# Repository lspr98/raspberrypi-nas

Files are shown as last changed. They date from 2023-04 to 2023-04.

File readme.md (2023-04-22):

# Raspberry Pi NAS Rack for up to 4 2.5"-SSDs
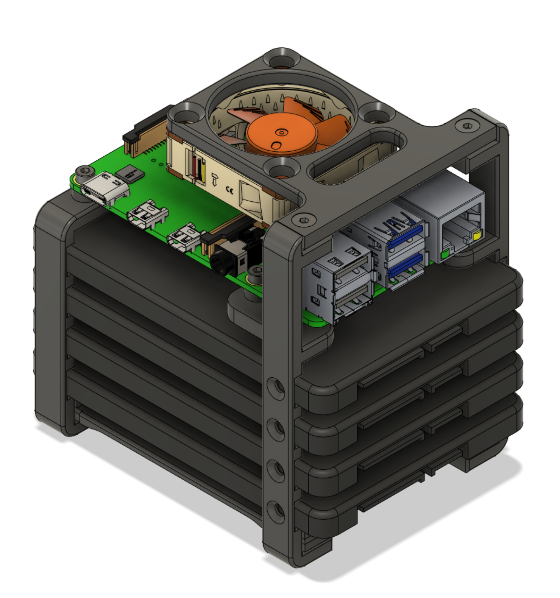
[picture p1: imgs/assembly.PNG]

## Highlights
- **Slim**: The rack is only 4mm wider than a 2.5" SSD and as long as a 2.5" SSD
- **Modular**: 2-bay and 4-bay version available, each with or without fan mount
- **Accessible**: All Raspberry Pi ports/pins are accessible without the fan
- **Ease-Of-Use**: Small nobs secure the SSDs without screws for quick swapping
- **Open-Source**: STEP-File with complete assembly available for easy modding

## Sourcing / BOM
Please refer to the [BOM file](./Sourcing/BOM.xlsx)

## Printing

At least 100mm x 100mm buildplate size is required.

Depending on what version of the NAS rack you want, you need to print different parts:
|Part Name|2-Bay|2-Bay with fan|4-Bay|4-Bay with fan|Support needed|
|---|---|---|---|---|---|
|40mm_fan_mount.stl| |1| |1|No|
|brace_long_side.stl|2|2|2|2|No|
|brace_short_side.stl|2|2|2|2|No|
|column_noshift_noscrew.stl|2|2| | |Touching Buildplate|
|column_noshift_noscrew_QUAD.stl| | |2|2|Touching Buildplate|
|column_shift.stl|1| | | |Touching Buildplate|
|column_shift_mirror.stl|1| | | |Touching Buildplate|
|column_shift_fan.stl| |1| | |Touching Buildplate|
|column_shift_fan_mirror.stl| |1| | |Touching Buildplate|
|column_shift_QUAD.stl| | |1| |Touching Buildplate|
|column_shift_QUAD_mirror.stl| | |1| |Touching Buildplate|
|column_shift_fan_QUAD.stl| | | |1|Touching Buildplate|
|column_shift_fan_QUAD_mirror.stl| | | |1|Touching Buildplate|

These are only recommendations and worked fine on my Ender 3:
|Settings|Value|
|---|---|
|Wall count|4|
|Top/Bottom Layers|4|
|Layer Height|0.2mm|
|Material|PLA|
|Infill|40%|
|Support|Refer to table above|

## Important Notes
When using multiple SSDs, make sure that the accumulated current draw across all USB ports do not surpass the maximum rated output. Also make sure that your power supply can handle the additional power requirements.
|RPi Model|Maximum rated output across all ports|
|---|---|
|Pi 2,3,4|1200mA|

Also consider the shared bandwith of the USB ports.

## CAD Credits
The 3D-models for the Screws, Nuts, SSDs, Raspberry and Fan are from GrabCAD:

|Model|Author|Link|
|---|---|---|
|M3x10 Screw|[Antonio Ghio](https://grabcad.com/antonio.ghio-1)|[Source](https://grabcad.com/library/hex-socket-countersunk-flat-head-screws-m3-1)|
|M3 Nut|[ioan skurka](https://grabcad.com/ioan.skurka-1)|[Source](https://grabcad.com/library/all-m3-sh-standard-screws-m3-hex-nut-and-flat-washer-for-m3-screw-1)|
|M2.5x10 Screw|[VIVEK AKASH](https://grabcad.com/vivek.akash-2)|[Source](https://grabcad.com/library/m2-5-0-45-hex-screw-5-10-15-20-25-30-mm-1)|
|M2.5 Nut|[Antonio Ghio](https://grabcad.com/antonio.ghio-1)|[Source](https://grabcad.com/library/nuts-and-washers-m2-5-1)|
|2.5" SSD|[Thin Pinstripes](https://grabcad.com/thin.pinstripes-1)|[Source](https://grabcad.com/library/u2-2-5in-ssd-1)|
|NF-A4x10 FLX|[Gerard](https://grabcad.com/gerard-84)|[Source](https://grabcad.com/library/noctua-fan-nf-a4x10-flx-4010-1)|
|Raspberry Pi 4 Model B|[Hasanain Shuja](https://grabcad.com/hasanain.shuja-1)|[Source](https://grabcad.com/library/raspberry-pi-4-model-b-1)|

## References
[1]: Rasberry Pi Documentation, [Link](https://www.raspberrypi.com/documentation/computers/raspberry-pi.html#universal-serial-bus-usb)

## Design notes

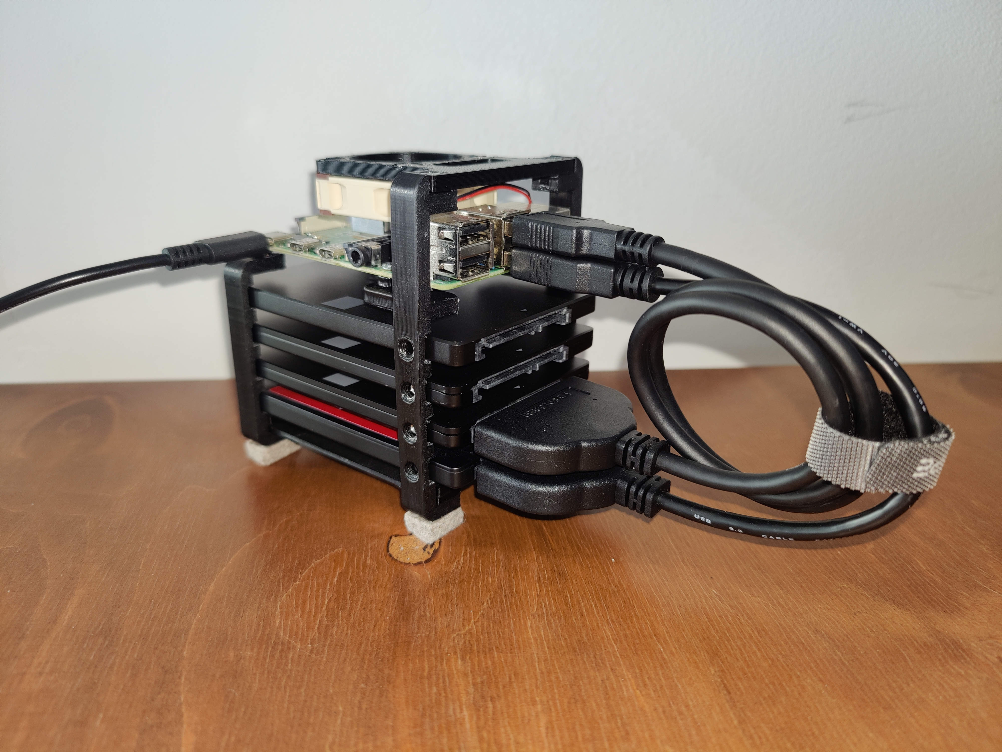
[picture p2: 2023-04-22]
imgs/photo_quad_with_fan.jpg

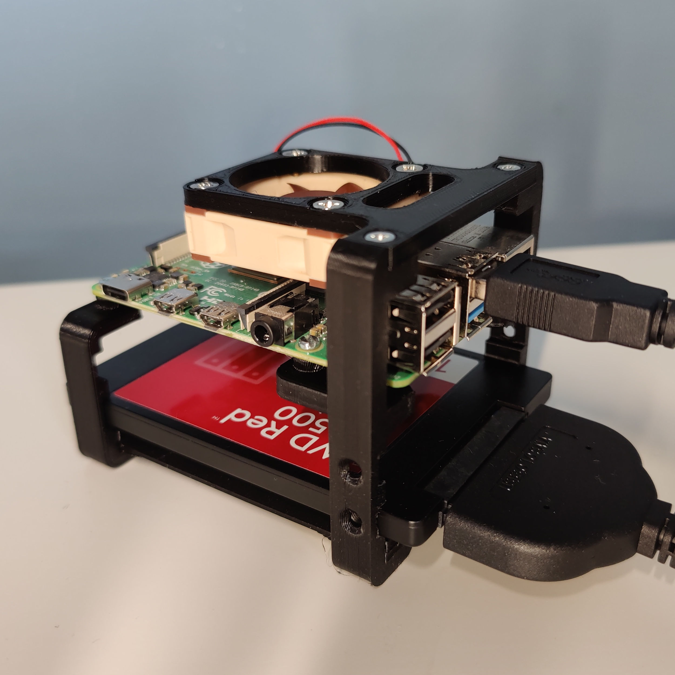
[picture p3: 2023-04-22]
imgs/photo_dual_with_fan.jpg

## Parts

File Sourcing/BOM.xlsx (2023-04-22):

Category | Description | Quantity (without fan) | Quantity (with fan) | Notes
Fasteners | M2.5 Nut | 4 | 4
 | M3 Nut | 4 | 6
 | M2.5x10 Sockethead | 4 | 4
 | M3x10 Countersunk | 4 | 6
 | Fan Mounting Screws | 0 | 4 | These should come with the fan
Elecronics | NF-A10 | 0 | 1
 | Raspberry Pi 1/2/3/4 | 1 | 1 | The rack versions without fan should be compatible with "knock-offs" as long as the mounting holes are identical
 | SATA to USB adapter | 1 to 4 | 1 to 4 | Depending on how many SSDs you plan to install

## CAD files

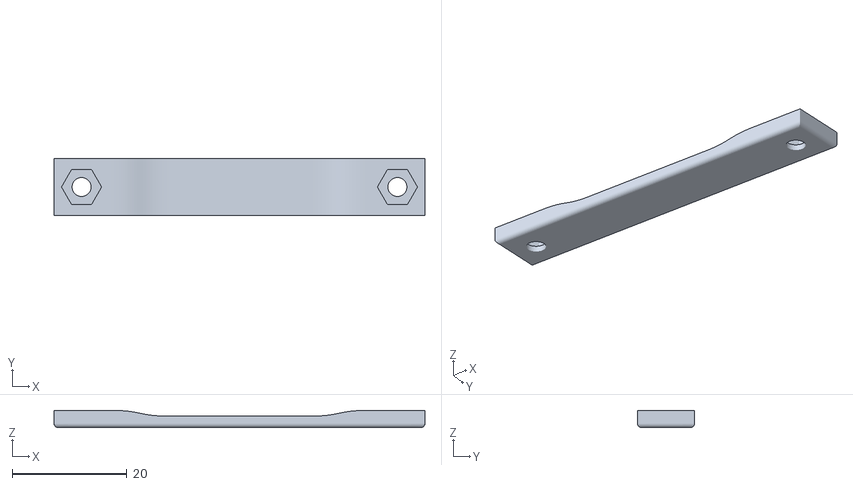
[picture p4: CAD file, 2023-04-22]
STL/brace_short_side.stl
64.6 x 10.0 x 3.00

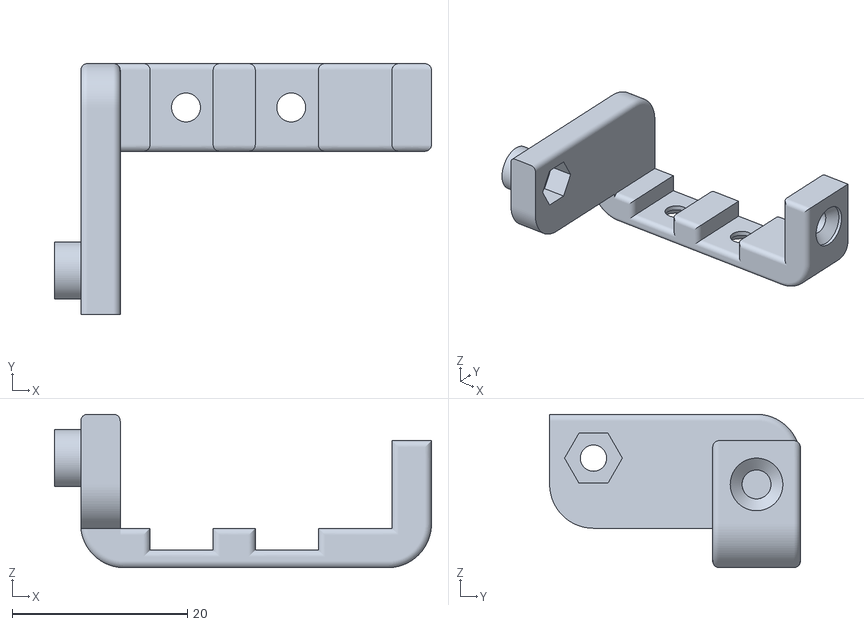
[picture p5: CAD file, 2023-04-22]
STL/column_shift_mirror.stl
43.0 x 28.6 x 17.5

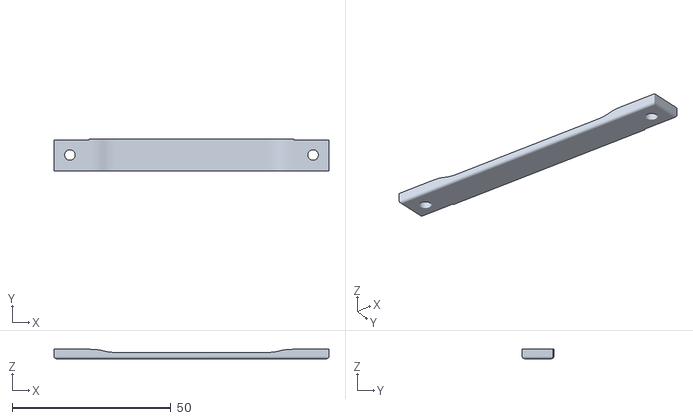
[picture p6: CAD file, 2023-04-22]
STL/brace_long_side.stl
86.6 x 10.0 x 3.00

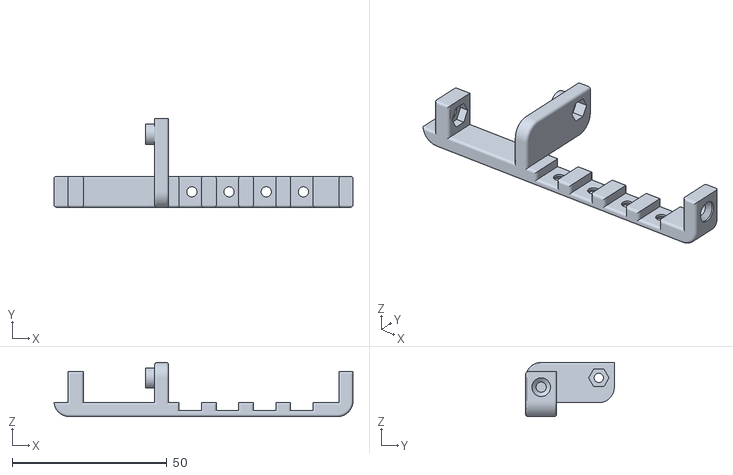
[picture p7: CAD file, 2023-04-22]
STL/column_shift_fan_QUAD.stl
96.5 x 28.6 x 17.5

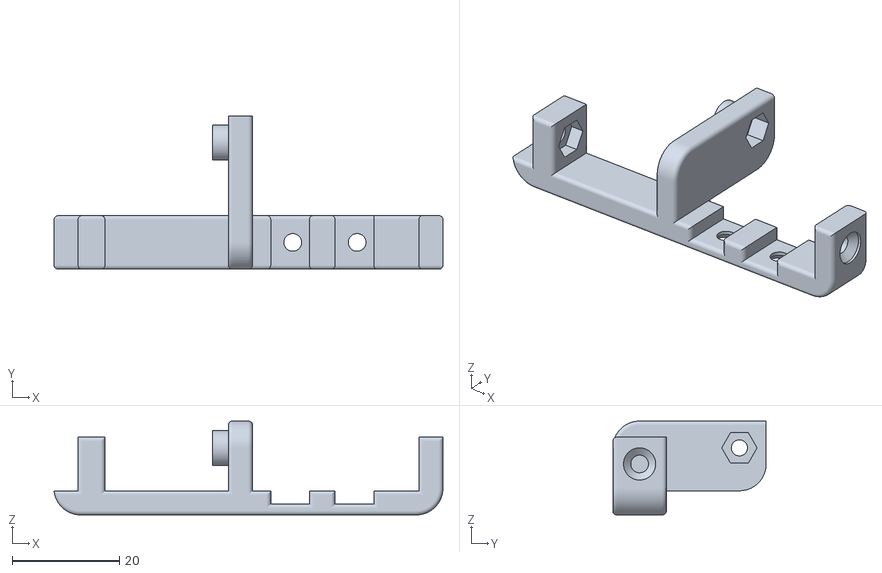
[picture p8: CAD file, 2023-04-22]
STL/column_shift_fan.stl
72.5 x 28.6 x 17.5

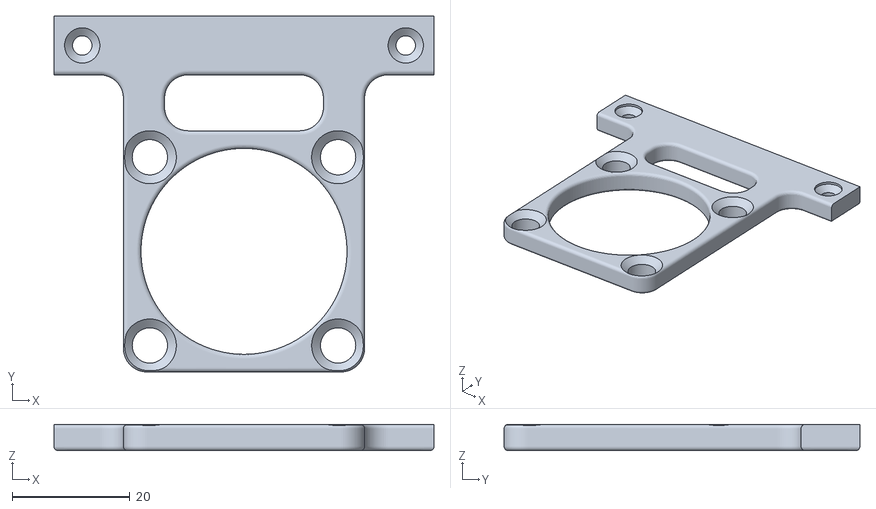
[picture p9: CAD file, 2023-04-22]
STL/40mm_fan_mount.stl
64.6 x 60.5 x 4.50

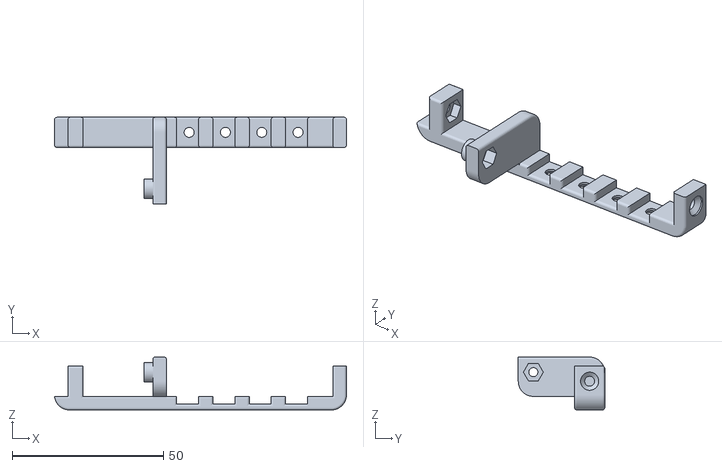
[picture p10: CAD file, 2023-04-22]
STL/column_shift_fan_QUAD_mirror.stl
96.5 x 28.6 x 17.5

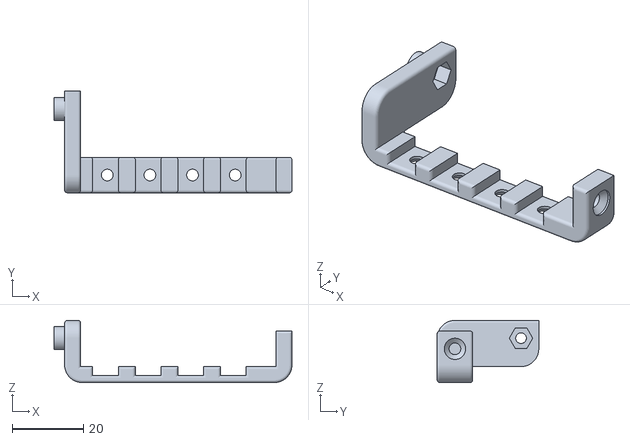
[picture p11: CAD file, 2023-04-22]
STL/column_shift_QUAD.stl
67.0 x 28.6 x 17.5

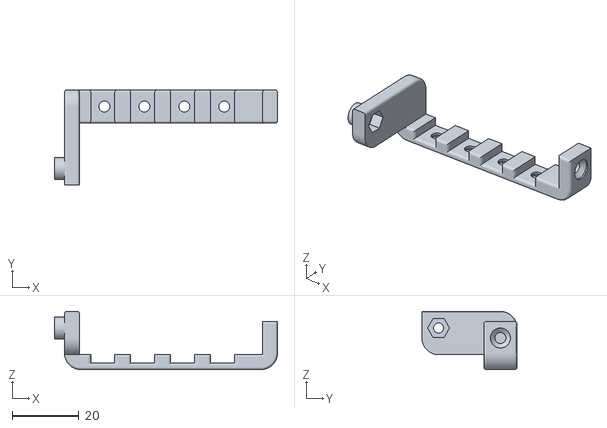
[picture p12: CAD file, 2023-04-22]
STL/column_shift_QUAD_mirror.stl
67.0 x 28.6 x 17.5

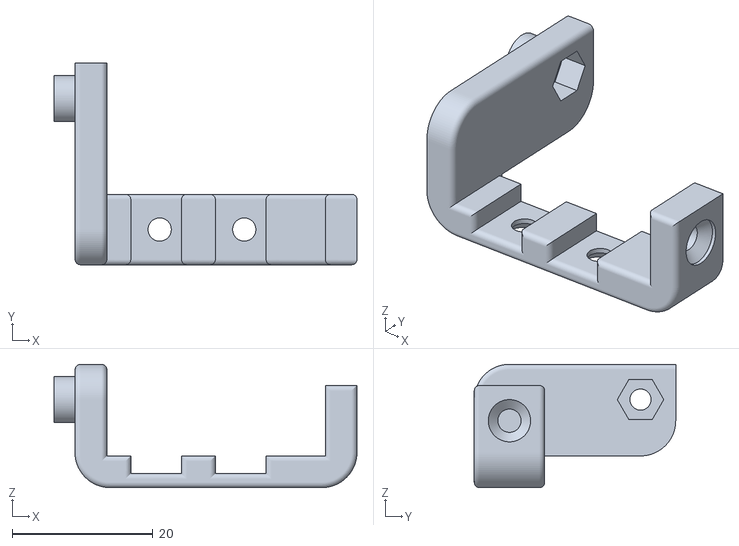
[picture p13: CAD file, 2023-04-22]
STL/column_shift.stl
43.0 x 28.6 x 17.5

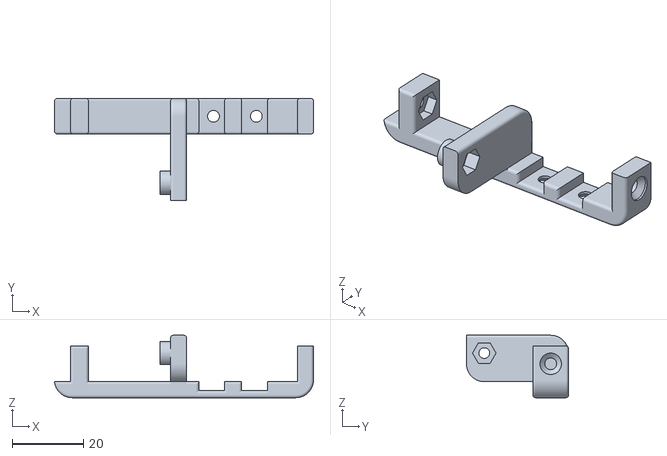
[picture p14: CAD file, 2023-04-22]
STL/column_shift_fan_mirror.stl
72.5 x 28.6 x 17.5

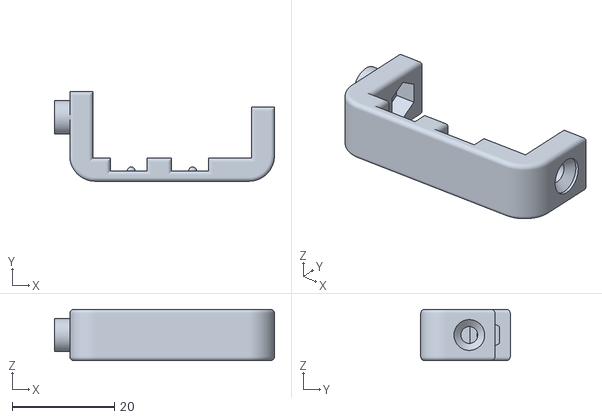
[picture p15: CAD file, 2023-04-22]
STL/column_noshift_noscrew.stl
43.0 x 17.5 x 10.0

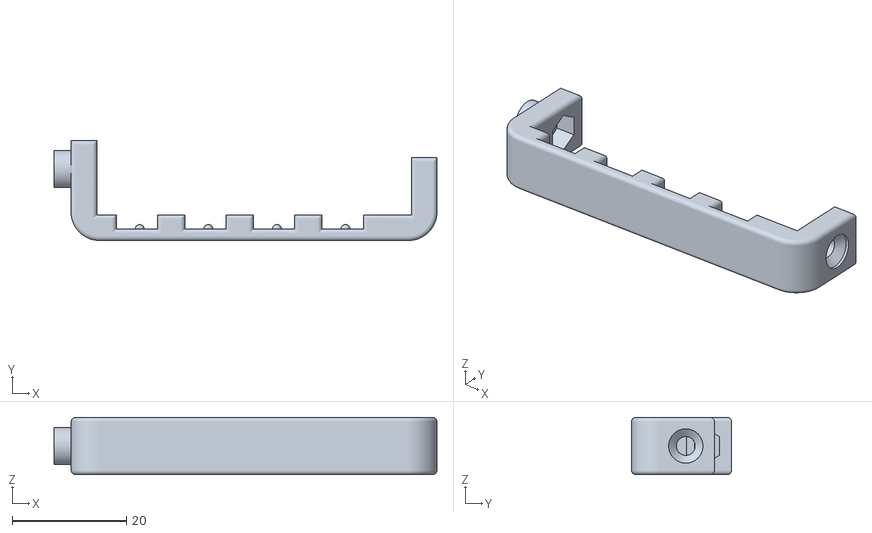
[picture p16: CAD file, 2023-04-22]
STL/column_noshift_noscrew_QUAD.stl
67.0 x 17.5 x 10.0
